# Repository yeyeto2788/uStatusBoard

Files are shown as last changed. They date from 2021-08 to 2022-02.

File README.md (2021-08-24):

# uStatusBoard
The uStatusBoard is a board designed to be used as simple notifier with 4 leds WS2812B (aka NeoPixels) to show the status
by changing the color of the led on the board.

You can use a marker to write down the condition/status of anything you're monitoring.

**Top view of the board (latest version)**

<p align="center">
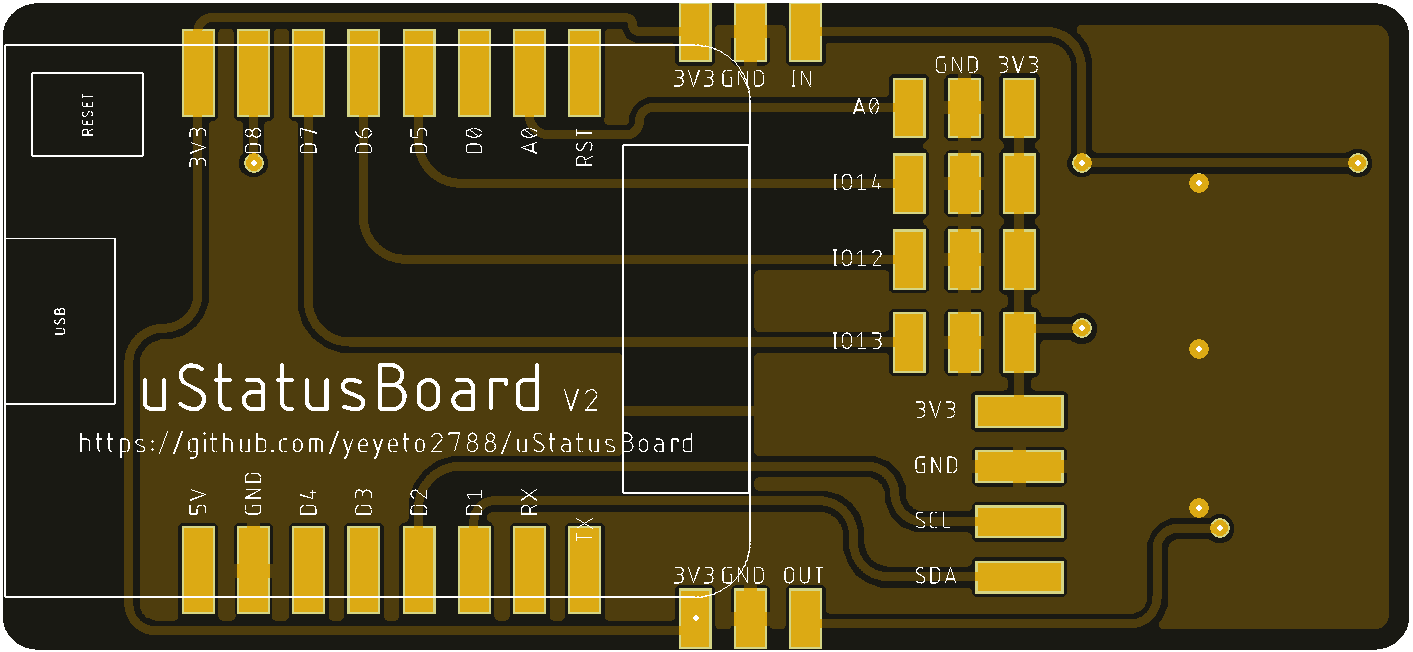
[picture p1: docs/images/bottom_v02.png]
Top View of the board

</p>

**Bottom view of the board (latest version)**

<p align="center">
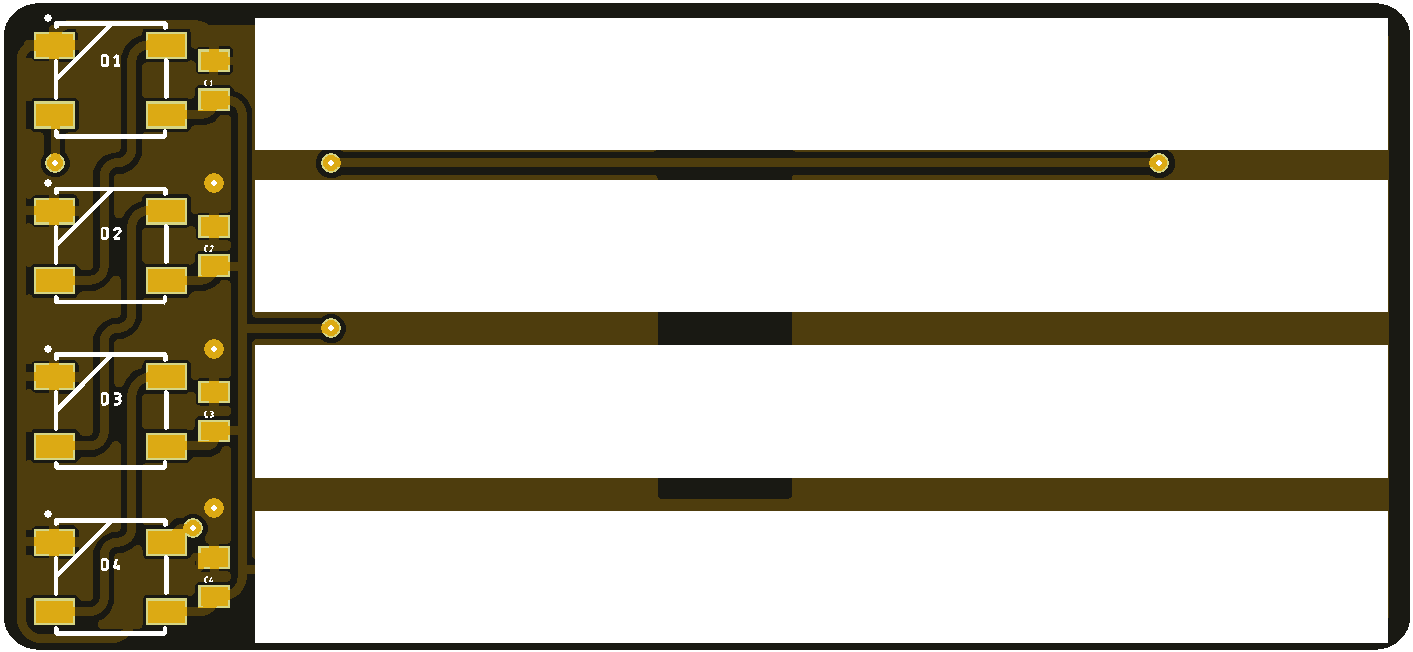
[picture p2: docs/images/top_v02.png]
Bottom view of the board

</p>

In order to use the board we will need a Wemos D1 mini (image below) which the board is soldered onto it.

**Wemos D1 mini board**

<p align="center">
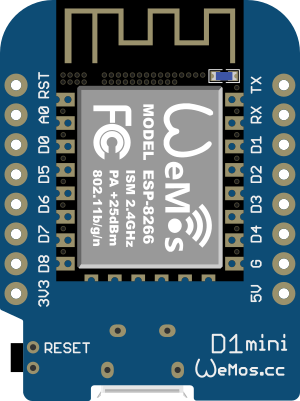
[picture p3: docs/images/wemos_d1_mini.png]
Wemos d1 mini board

</p>

**Note:** There is no need to use specifically the Wemos D1 mini board, another board can used with this uStatusBoard.

## Structure for the Repository

```
Main Repository Folder(uStatusBoard)
        └── docs Folders
        |        |
        |        └── images folder
        └── examples Folder
        |   |
        |   └── example scripts
        |     
        ├── hardware Folder
        |     |
        |     └── version folders (Schematics and board design)
        |
        └── status_board.py (module)
        |
        └── README (This document.)
```

## Usage examples
To use the code (written in [MicroPython](https://micropython.org/)) we will just upload the module `status_board.py` and in the REPL we can start playing with it.

```console
>>> from status_board import StatusBoard
>>> board = StatusBoard()
>>> board.pin
Pin(15)
>>> board.brightness
255
```

Take into account that we are instantiated the object with the default attributes as seen in the REPL output above.

So now let's play a bit with it.

```console
>>> board.color_all('blue')
>>> board.color_all('red')
>>> board.color_all('green')
>>> board.color_all('white')
>>> board.color_all('nocolor')
```

This colors are defined on the `StatusBoard.colors` attribute which can be accessed any time

```console
>>> board.colors
{'cyan': [0, 1, 1], 'nocolor': [0, 0, 0], 'magenta': [1, 0, 1], 'blue': [0, 0, 1], 'yellow': [1, 1, 0], 'white': [1, 1, 1], 'green': [0, 1, 0], 'red': [1, 0, 0]}
```

Now let's turn off all the leds

```console
>>> board.clear_all()
```

If you want to know more about what methods the `StatusBoard` has head over to the [status_board.py](./status_board.py) script.

#### If you want **more examples** head over the [examples folder](./examples/).

___
## Any feedback is highly appreciated! 

Please, if you see any error open an issue on this repo.

___
## Useful links:

[MicroPython](https://micropython.org/)

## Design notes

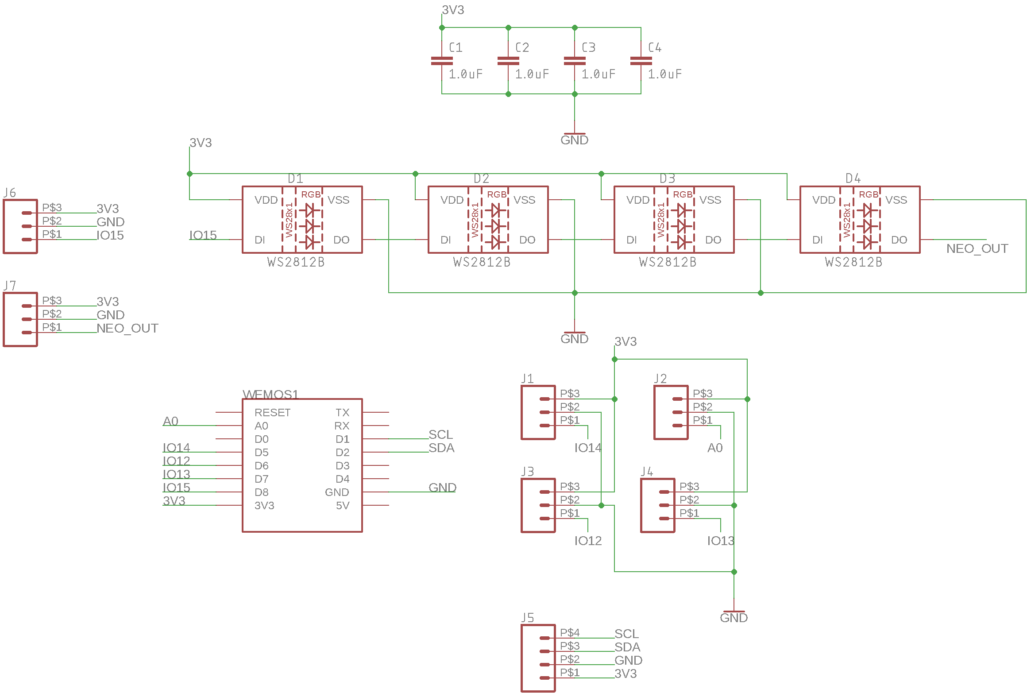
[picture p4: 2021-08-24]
hardware/V02/schematics_v02.png

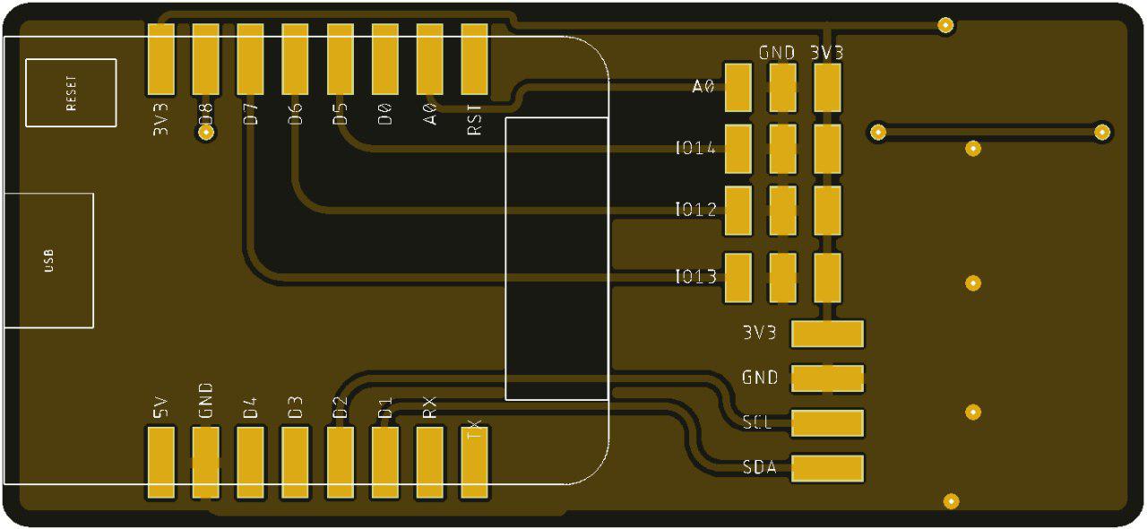
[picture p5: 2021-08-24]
docs/images/bottom_v01.jpg

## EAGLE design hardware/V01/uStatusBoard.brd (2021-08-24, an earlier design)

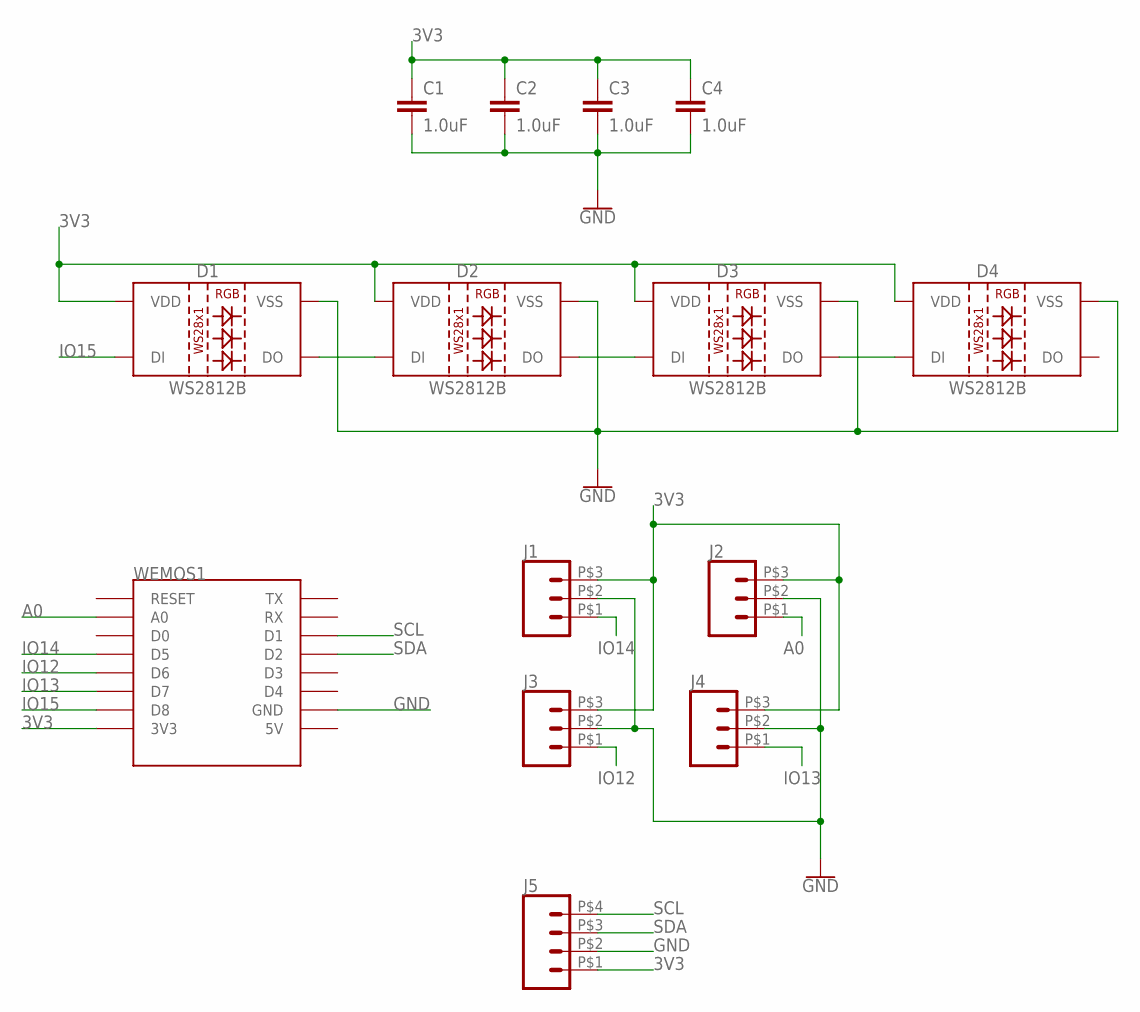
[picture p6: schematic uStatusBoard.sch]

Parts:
C1, C2, C3, C4: 1.0uF; 0805
D1, D2, D3, D4: WS2812B
J1, J2, J3, J4: CONN_031X03_SMD; 1X03_SMD
J5: CONN_041X04_SMD; 1X04_SMD
WEMOS1: WEMOS-D1-MINIWEMOS_SMD; WEMOS-SMD

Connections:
3V3: C1.1, C2.1, C3.1, C4.1, D1.1 (VDD), D2.1 (VDD), D3.1 (VDD), D4.1 (VDD), J1.P$3 (3), J2.P$3 (3), J3.P$3 (3), J4.P$3 (3), J5.P$1 (1), WEMOS1.3V3
A0: J2.P$1 (1), WEMOS1.A0
GND: C1.2, C2.2, C3.2, C4.2, D1.3 (VSS), D2.3 (VSS), D3.3 (VSS), D4.3 (VSS), J1.P$2 (2), J2.P$2 (2), J3.P$2 (2), J4.P$2 (2), J5.P$2 (2), WEMOS1.GND
IO12: J3.P$1 (1), WEMOS1.D6
IO13: J4.P$1 (1), WEMOS1.D7
IO14: J1.P$1 (1), WEMOS1.D5
IO15: D1.4 (DI), WEMOS1.D8
unnamed: D1.2 (DO), D2.4 (DI)
unnamed: D2.2 (DO), D3.4 (DI)
unnamed: D3.2 (DO), D4.4 (DI)
SCL: J5.P$4 (4), WEMOS1.D1
SDA: J5.P$3 (3), WEMOS1.D2

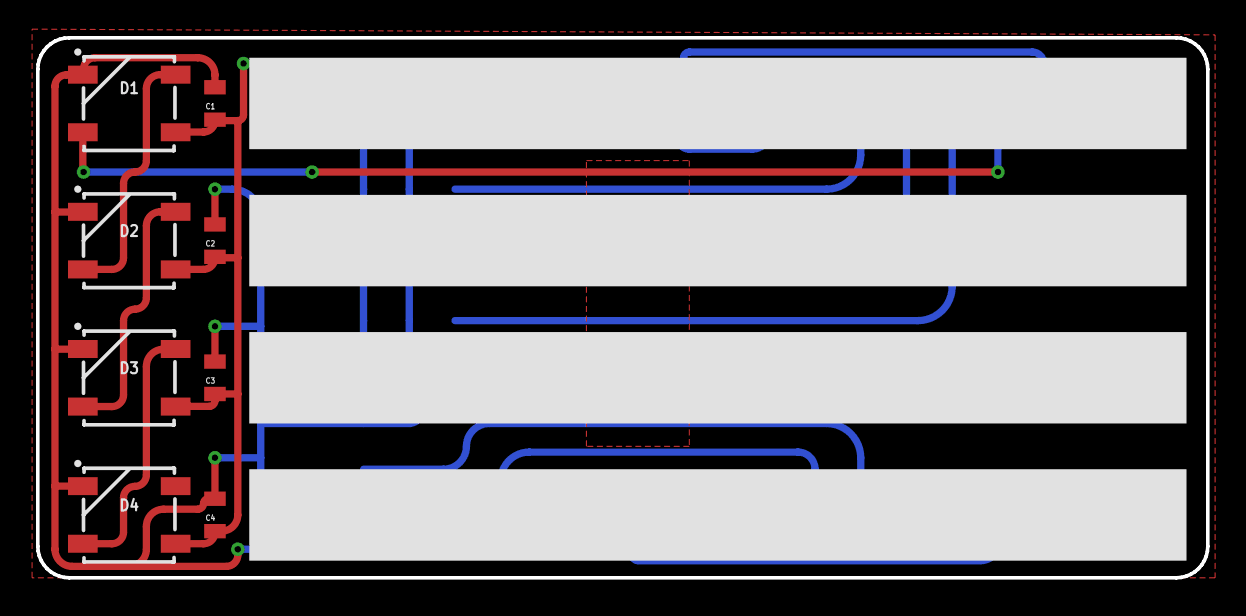
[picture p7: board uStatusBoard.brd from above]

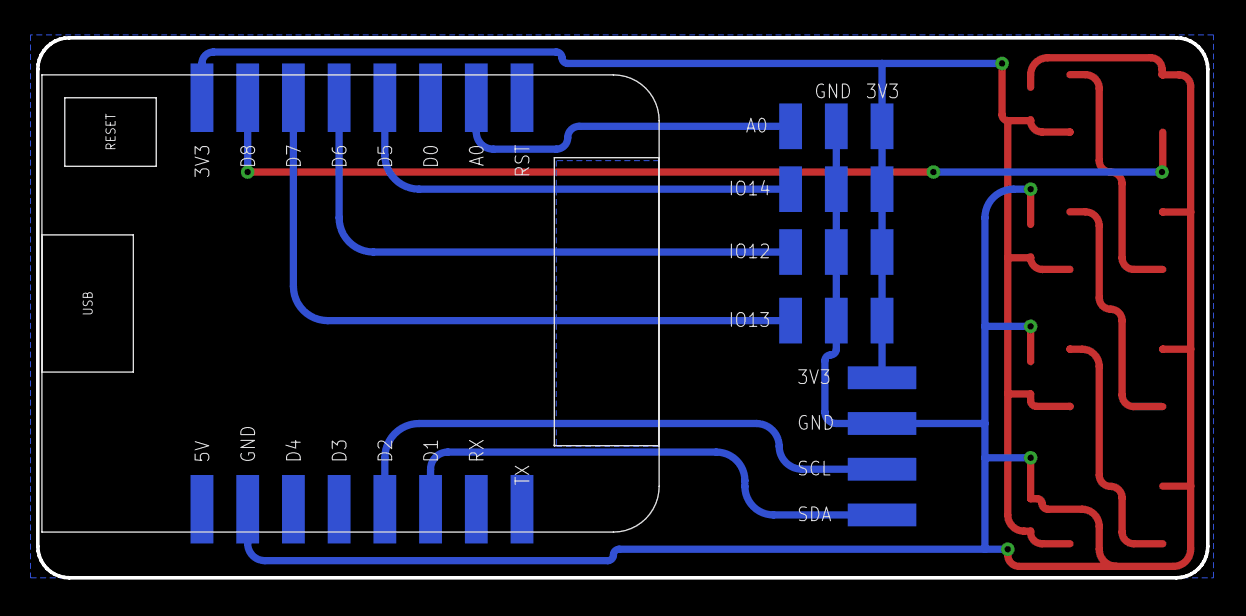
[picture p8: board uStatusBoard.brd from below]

Board: 2 copper layers, 65.0 x 30.0 mm, 14 parts (6 on the bottom side), 12 nets.

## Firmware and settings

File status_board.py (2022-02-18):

"""
Simple module to used with the uStatusBoard.

It uses four (4) WS2812B (aka Neopixels) connected
by default to pin 15 on the ESP8266

-------------------------------
| |_| LED 0  #################|
|  _                          |
| |_| LED 1  #################|
|  _                          |
| |_| LED 2  #################|
|  _                          |
| |_| LED 3  #################|
-------------------------------
More info: https://github.com/yeyeto2788/uStatusBoard
"""
import machine
import neopixel
import urandom


class StatusBoard:
    """
    StatusBoard object to handle all actions on the board.

    Attributes:
        pin (machine.Pin): Instantiated on pin 15 by default.
        neopixels: Count of neopixels on the board (4 by default).
        neostrip (neopixel.NeoPixel): Instance of NeoPixel where all
        change are applied to it.
        brightness (int): level applied on each color of the led (0 - 255).
        colors (dict): All available colors by combining RGB states.
    """

    def __init__(self, pin=15, neopixels=4, brightness=255):
        self.pin = machine.Pin(pin, machine.Pin.OUT)
        self.neopixels = neopixels
        self.neostrip = neopixel.NeoPixel(self.pin, self.neopixels)
        self.brightness = brightness
        self.colors = {
            "nocolor": [0, 0, 0],
            "blue": [0, 0, 1],
            "green": [0, 1, 0],
            "cyan": [0, 1, 1],
            "red": [1, 0, 0],
            "magenta": [1, 0, 1],
            "yellow": [1, 1, 0],
            "white": [1, 1, 1],
        }
        self.clear_all()

    def _get_color_brightness(self, color):
        """
        Cycle through the colors and find the given key color and return the
        given color matching the brightness level.

        Args:
            color (str): Name of the color get the value from.

        Returns:
            List with color at a brightness level.
        """
        return [(c_value * self.brightness) for c_value in self.colors[color.lower()]]

    def set_pixel_color(self, pixel, color):
        """
        Set given color based on the brightness level on a given board LED.

        Args:
            pixel (int): Led position on the board.
            color (str): Name of the color.

        Returns:
            None.
        """
        self.neostrip[pixel] = self._get_color_brightness(color)
        self.neostrip.write()

    def clear_all(self):
        """
        Turn off all LEDs on the board.

        Returns:
            None.
        """
        for pixel in range(self.neopixels):
            self.neostrip[pixel] = (0, 0, 0)
        self.neostrip.write()

    def color_all(self, color):
        """
        Set given color based on the brightness level on all LEDs on the board.

        Args:
            color (str): Name of the color.

        Returns:
            None.
        """
        for pixel in range(self.neopixels):
            self.neostrip[pixel] = self._get_color_brightness(color)
        self.neostrip.write()

    def _get_random_int(self):
        """
        Generate a seudo random integer from 0 to 255.

        Returns:
            Integer generated.
        """
        int_return = urandom.getrandbits(8)
        if 0 < int_return < 256:
            return int_return
        else:
            return 0

    def set_pixel_random_color(self, pixel):
        """
        Create a random color using the `_get_random_int` method for
        red, green and blue.

        Args:
            pixel (int): Led position on the board.

        Returns:
            None.
        """
        r_color = self._get_random_int()
        g_color = self._get_random_int()
        b_color = self._get_random_int()
        color = [r_color, g_color, b_color]
        self.neostrip[pixel] = color
        self.neostrip.write()

    def get_pixel_raw_color(self, pixel):
        """
        Return the value of the given pixel in [R, G, B] format.

        Args:
            pixel (int): Pixel number

        Returns:
            List the real color on the pixel.
        """
        return self.neostrip[pixel]

    def set_pixel_raw_color(self, pixel, color):
        """
        Set pixel color to a given color [R, G, B] format.

        Args:
            pixel (int): Pixel number
            color (list): Color in [R, G, B] format.

        Returns:
            None.
        """
        self.neostrip[pixel] = color
        self.neostrip.write()

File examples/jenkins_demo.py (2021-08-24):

"""
Simple script to set build status on uStatusBoard
builtin leds.

Based on the status, the led will light up green, red
or yellow in order to show each build status.

"""
import time

try:
    import urequests as requests
except ImportError:
    import requests

from status_board import StatusBoard


class Jenkins:
    """
    Class to handle all needed operations to get the
    build status and color assigned to it.

    Attributes:
        last_build: URL to fetch last build regardless its status.
        status_color: Match between color and statuses.
        user: Jenkins username.
        psswd: Password used to authenticate on Jenkins.
        project: Job on Jenkins to retrieve the status from.
        host: IP:port to communicate with Jenkins.

    """

    last_build = "http://{auth}{host}{job}/lastBuild/api/json"
    status_color = {
        "FAILURE": "red",
        "SUCCESS": "yellow",
        "UNSTABLE": "green",
    }

    def __init__(self, host, user, password, job):
        self.user = user
        self.psswd = password
        self.auth = ""
        self.host = host
        self.project = job
        self.set_authorization(user, password)
        self._set_url()

    def set_authorization(self, user, password):
        """
        Set the value for the authorization part of the url.

        Args:
            user (str): Username.
            password (str): Password.

        Returns:
            None.
        """
        if user is not None and password is not None:
            self.auth = "{user}:{password}@".format(user=user, password=password)
        else:
            self.auth = ""

    def _set_url(self):
        """
        Add values on the URL in order to retrieve data.

        Returns:
            None.
        """
        self.url = self.last_build.format(
            auth=self.auth, host=self.host, job=self.project
        )

    def get_status_color(self, status):
        """
        Based on a status return its color assigned.

        Args:
            status (str): status to look the color for.

        Returns:
            String with the color assigned to the status.
        """
        return self.status_color[status]

    def get_build_status(self):
        """
        Make an HTTP request to jenkins API and retrieve the build
        information to look for the build status on it.

        Returns:
            String with the `result` attribute on response.
        """
        querystring = {"depth": "1"}

        payload = ""
        headers = {
            "Connection": "keep-alive",
            "Content-Type": "application/json",
            "cache-control": "no-cache",
        }
        response = requests.get(
            self.url, data=payload, headers=headers, params=querystring
        )
        data = response.json()["result"]
        response.close()
        return data


board = StatusBoard()
USER = "username"
PASS = "password"
ENDPOINT = '"jenkins.com:9090/"'

jenkins_project1 = Jenkins(host=ENDPOINT, user=USER, password=PASS, job="job/project1")
jenkins_project2 = Jenkins(host=ENDPOINT, user=USER, password=PASS, job="job/project2")

while True:
    project1_status = jenkins_project1.get_build_status()
    project2_status = jenkins_project2.get_build_status()
    build1_color = jenkins_project1.get_status_color(project1_status)
    build2_color = jenkins_project2.get_status_color(project2_status)
    board.set_pixel_color(0, build1_color)
    board.set_pixel_color(1, build2_color)
    time.sleep(10)

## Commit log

2019-05-28 Fix typos on module and add new function
    [status_board.py]
2019-05-28 Add images to repo and README and some info on the file.
    [uStatusBoard.brd, uStatusBoard.sch]
2019-05-28 Add hardware v2 files and reflect changes on the README.
    [uStatusBoard.brd, uStatusBoard.sch]
2019-05-29 Add another usage example of the board and fix typo on image naming.
    [dht_status.py]
2019-05-30 Fix some lint issues
    [status_board.py]

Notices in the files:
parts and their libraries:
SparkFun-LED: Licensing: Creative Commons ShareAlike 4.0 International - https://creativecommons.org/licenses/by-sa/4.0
